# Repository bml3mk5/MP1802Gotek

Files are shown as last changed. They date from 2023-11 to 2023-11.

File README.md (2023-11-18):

# VFOインターフェース for MP-1802 / MP-1870 on 日立ベーシックマスターレベル３ / MB-S1

## フォルダ構成

    Board/ ......................... 基板設計(KiCAD Version 6)

-----
# VFO Interface for MP-1802 / MP-1870 on HITACH BASIC MASTER LEVEL3 / MB-S1

## Folders:

    Board/ ......................... Circuit board design(KiCAD Version 6)

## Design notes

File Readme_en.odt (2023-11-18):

# HITACH BASIC MASTER LEVEL3 / MB-S1

# VFO Interface for MP-1802 / MP-1870

Designed by Sasaji 2022 Rev. 0.1.2

This is an interface board connecting between a floppy disk drive and MP-1802 / MP-1870, the FD interface card on a PC.

You can use this on HITACHI BASIC MASTER LEVEL3 / Mark II / Mark5 and MB-S1.

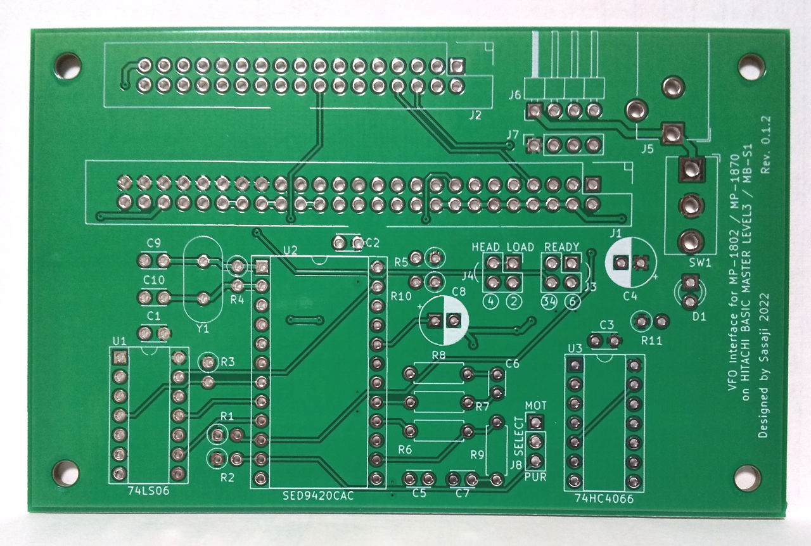
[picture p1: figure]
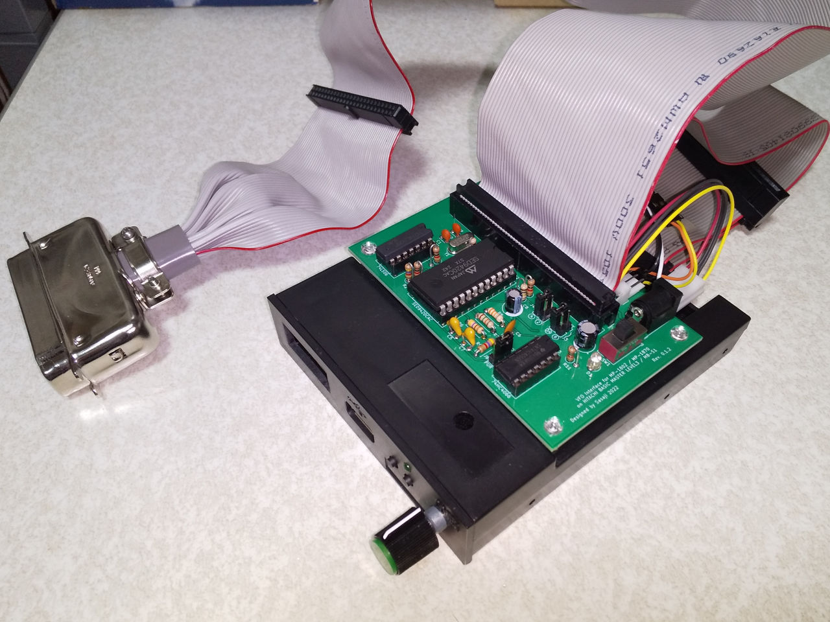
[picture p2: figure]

Connecting to the GOTEK floppy emulator

# Preparing

To use this board, you need to prepare the following :

- The FD interface card MP-1802 or MP-1870 must be present on the computer.
- FDD Emulator (GOTEK)
- Power: +5V, 1A (A switching AC adapter etc.)
- Cable to connect with the computer: 50-pin Amphenol <-> 50-pin IDC connector (2.54mm pitch x 2 rows)
- Cable to connect with FDD: 34-pin IDC connector cable (2.54mm pitch x 2 rows)

# Role of each part

Power input +5V DC Barrel Jack (Center plus) Power input +5V EI connector (+5V,Gnd,Gnd,N/C) Connect to FDD Connect to PC Power output +5V Connect to FDD (Linked with power switch) Power switch Jumper Jumper + -

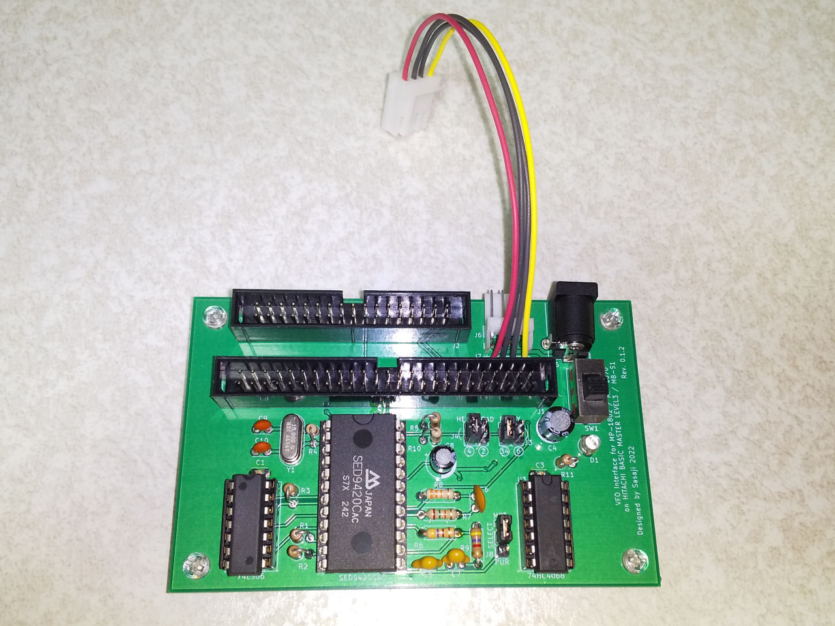
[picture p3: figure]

# Jumper pins

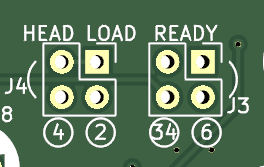
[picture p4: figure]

READY:

Select which the READY signal from the FDD is coming from.

pin34 or pin6

Short pins vertically.

HEAD LOAD:

Select which the HEAD LOAD signal from the computer is coming from.

pin4 or pin2

Short pins vertically.

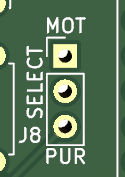
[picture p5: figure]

SELECT:

Selects the behavior of the DRIVE SELECT signal.

- MOT(Short to 1-2)：Connect the signal while the MOTOR signal is ON.
- PUR(Short to 2-3)：Always connect the signal.

# Pinout of the connector

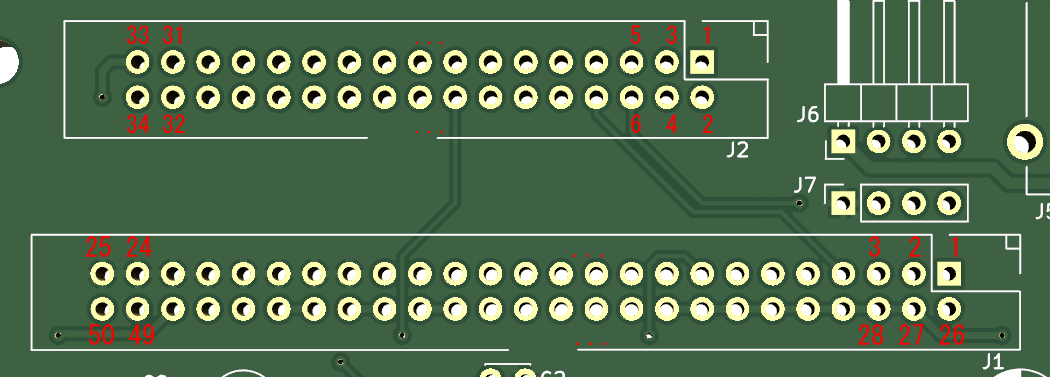
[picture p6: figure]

[Attention] The direction of silk printing is reversed. Correctly, the notch is on the upper side (pin 1 side).

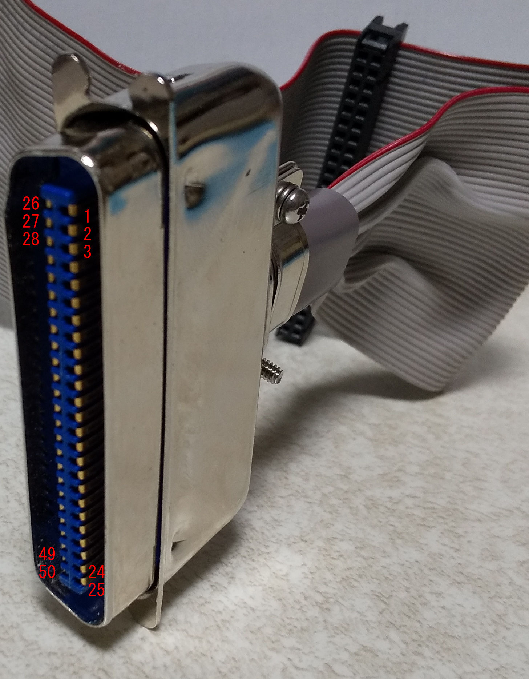
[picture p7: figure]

### When making your own 50-pin cable

There is a protrusion near pin 26 on the MP-1802/MP-1870 side, so bend this part on the cable side so that it does not hit the protrusion.

# Precautions for use

- Connect only one of the power input J5 (DC jack) and J6 (EI connector).
- Pin 4 (+12V line) of J6 is not connected to anything. When using an FDD that requires +12V, connect the power connector without going through this board.
- If the physical FDD pull-up resistance value is low, drive select may not function properly. In this case, see “About optional functions” section.
- This board is a prototype. Please note that we do not consider the noise generated during use or deterioration over time.

## No Warranty

We are not responsible for any damage caused by this board.

Use this board at your own risk.

## Web Site

GitHub(https://github.com/bml3mk5/MP1802Gotek)

Sasaji (sasaji@s-sasaji.ddo.jp)

http://s-sasaji.ddo.jp/bml3mk5/

(Twitter: https://twitter.com/bml3mk5)

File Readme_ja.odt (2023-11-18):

# 日立ベーシックマスターレベル３/ MB-S1用

# VFOインターフェース for MP-1802 / MP-1870

Designed by Sasaji 2022 Rev. 0.1.2

フロッピーディスクドライブとFDインターフェースMP-1802/MP-1870の間に接続する拡張ボードです。

日立ベーシックマスターレベル３/マークII/マーク5およびMB-S1で使用できます。


GOTEKを接続したところ

# 準備するもの

この基板を使用するには、以下のものを別途用意する必要があります。

- 本体側にFDインターフェースカード MP-1802またはMP-1870があること。
- FDDはエミュレータ(GOTEK)または2Dのもの。
- 電源：+5V, 1A以上（スイッチングACアダプタ など）
- 本体側と接続するケーブル：50ピンアンフェノール　⇔ 50ピン IDCコネクタ(2.54mmピッチ x2列)
- FDD側と接続するケーブル：34ピンIDCコネクタケーブル(2.54mmピッチ x2列)

# 各部の役割

電源入力 ＋５V DCジャック （中心が＋） 電源入力 ＋５V EIコネクタ (+5V,Gnd,Gnd,N/C) FDDと 接続 本体側と 接続 電源出力 ＋５V FDDに接続 （電源スイッチと連動） 電源スイッチ ジャンパー ジャンパー + -


# ジャンパピン


READY:

FDDからくるREADY信号がどのピンから来ているかを選択します。

ピン34 または ピン6

どちらかを縦方向にショートさせてください。

HEAD LOAD:

本体側からくるHEAD LOAD信号をどのピンに送るか選択します。

ピン4 または ピン2

どちらかを縦方向にショートさせてください。


SELECT:

DRIVE SELECT信号の挙動を選択します。

- MOT側(1-2をショート)：MOTOR信号がONのときのみFDDに接続します。
- PUR側(2-3をショート)：常にFDDに接続します。

# コネクタのピン配置


【注意】シルク印刷の向きが逆になっています。正しくは、切り欠きが上側(ピン1側)になります。


### 50ピンケーブル自作時の注意点

MP-1802/MP-1870側には、ピン26近くに出っ張りがあるため、ケーブル側はこの部分をまげて出っ張りに当たらないようにします。

# 使用上の注意

- 電源入力J5(DCジャック)とJ6(EIコネクタ)はどちらか一方のみ接続してください。
- J6のピン4(+12Vライン)はどこにも接続していません。+12Vが必要なFDDを使用する場合、電源コネクタはこの基板を経由せずに接続してください。
- 物理FDDのプルアップ抵抗値が低い場合、ドライブセレクトが正常に機能しない場合があります。この場合は「オプション機能について」に記述しているU3のピンをショートさせる処置を行ってください。
- この基板は試作品です。使用中に発生するノイズや経年劣化などに対しての考慮は全くしていませんので予めご了承ください。

## 免責事項

この基板によって発生したいかなる損害についても当方は一切責任を負いません。

この基板を使用するにあたってはすべて自己責任で行ってください。

## Webページ

この資料や基板データなどはGitHub(https://github.com/bml3mk5/MP1802Gotek)に置いています。

連絡先：

Sasaji (sasaji@s-sasaji.ddo.jp)

http://s-sasaji.ddo.jp/bml3mk5/

(Twitter: https://twitter.com/bml3mk5)

## 改訂履歴

第2版: 物理FDD使用時の注意点を追加。図内の脚注を修正。

初版: 新規作成。

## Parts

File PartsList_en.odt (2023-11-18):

# HITACH BASIC MASTER LEVEL3 / MB-S1

# VFO Interface for MP-1802 / MP-1870

Designed by Sasaji 2022 Rev. 0.1.2

# Parts list

Parts Number | Parts Name | Qty. | Description
C1~C2 | Ceramic Capacitor | 2 | 0.1uF
C4 | Electrolytic Capacitor | 1 | 100uF, 10V~
C5, C7 | Ceramic Capacitor | 2 | 0.01uF
C6 | Ceramic Capacitor | 1 | 3300pF
C8 | Electrolytic Capacitor | 1 | 22uF, 10V~
C9, C10 | Ceramic Capacitor | 2 | 22pF
R1, R3, R5, R11, R12 | Carbon Resistor | 5 | 1KΩ, 1/4W~
R2, R9 | Carbon Resistor | 2 | 4.7KΩ, 1/4W~
R4 | Carbon Resistor | 1 | 1MΩ, 1/4W~
R6 | Carbon Resistor | 1 | 470Ω, 1/4W~
R7 | Carbon Resistor | 1 | 15KΩ, 1/4W~
R8 | Carbon Resistor | 1 | 33KΩ, 1/4W~
R10 | Carbon Resistor | 1 | 100KΩ, 1/4W~
U1 | TTL Logic IC | 1 | 74LS06, DIP14
U2 | VFO IC | 1 | SED9420C or SED9420CAC DIP24, 600mil
Y1 | Crystal Oscillator | 1 | 16MHz
D1 | LED | 1 | Power Lamp 3mmΦ~
SW1 | Power Switch | 1 | SPDT SS12D10 etc.
J1 | BOX Header | 1 | 25pins x2rows 2.54mm pitch straight
J2 | BOX Header | 1 | 17pins x2rows 2.54mm pitch straight
J3, J4 | Jumper | 2 | Pinheader 2pin x2rows 2.54mmpitch straight
J5 | DC Jack | 1 | Barrel Jack 2.1mmΦ PJ-102 etc.
J6 | Power Connector | 1 | EI connector male 4pins L angled (3.5inch FDD)

## Optional Parts

C3 | Ceramic Capacitor | 1 | 0.1uF
U3 | CMOS Logic IC | 1 | 74HC4066 or 4066(*1), DIP14
J8 | Jumper | 1 | Pinheader 3pins x1row 2.54mm pitch straight
J7 | | 1 | Connect to 4 cables
* | FDD Connector | 1 | EIconnector female 4pins straight Connect from J7

(*1) See “About optional functions” section.

# Precautions for assembly

## * This board has some problems.

Connect resistor R12 between pin 3 of U1 and Vcc.

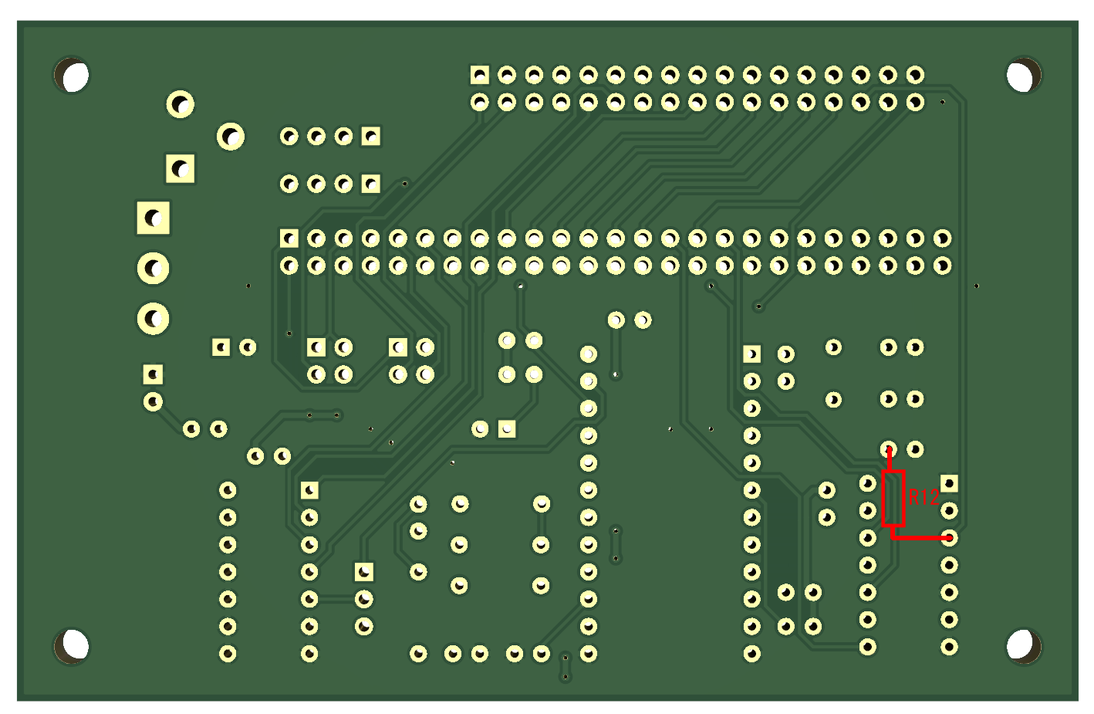
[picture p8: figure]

The notch of the BOX header is on the upper side.

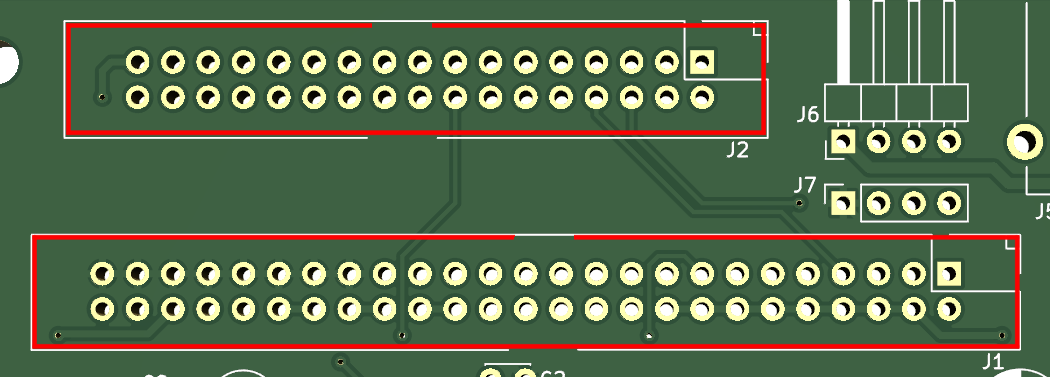
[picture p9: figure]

The anode (+) of the LED D1 is the lower side and the cathode (-) is the upper side.

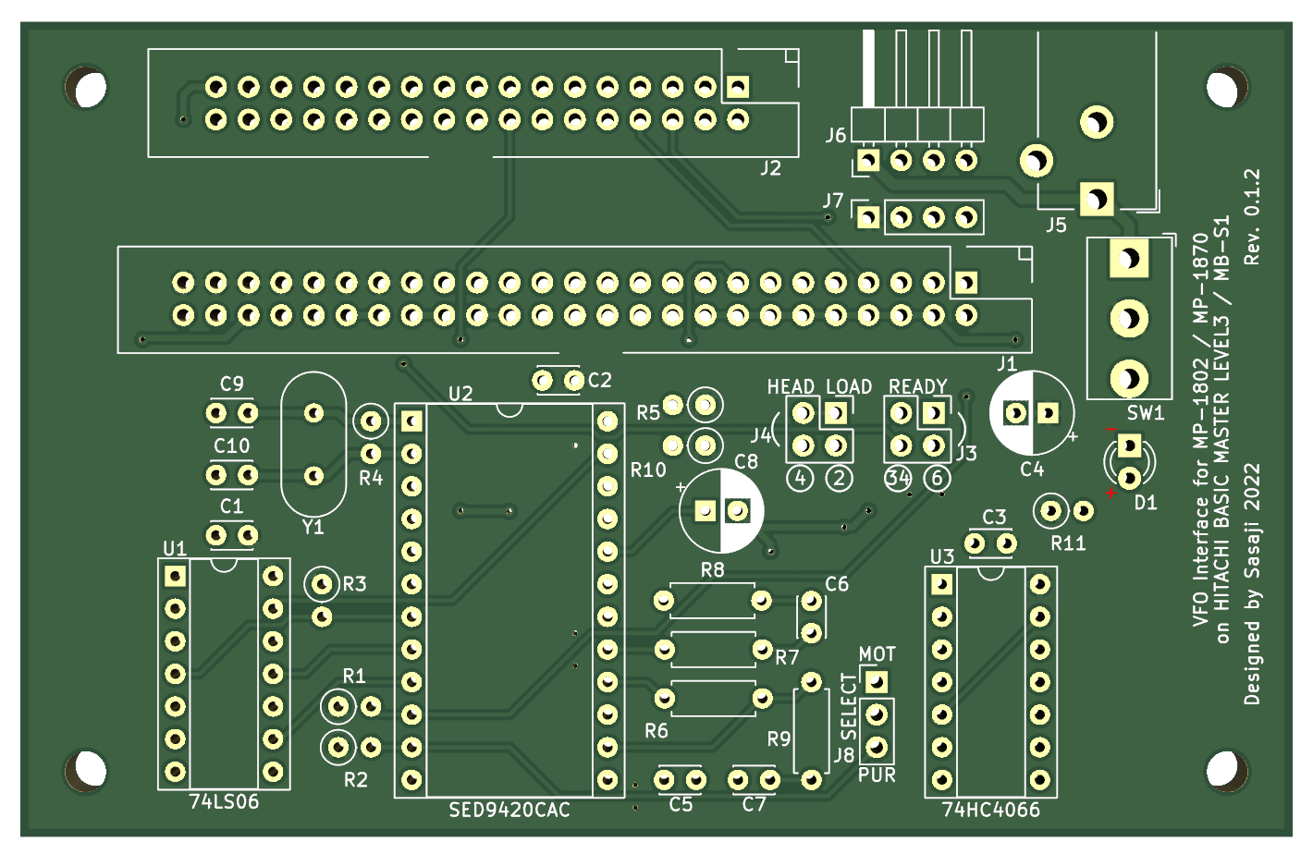
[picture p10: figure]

# About optional functions

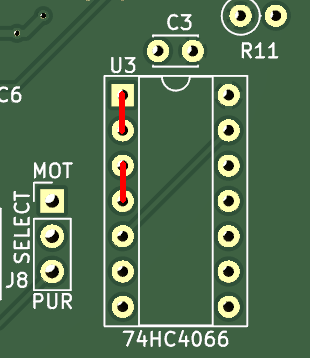
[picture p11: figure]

### About U3

The 74HC4066 (U3) connects the DRIVE SELECT signal to the FDD while the MOTOR signal is ON.

You can omit this feature if always connect it.

If omit U3:

- Short to 1-2 and 3-4 on U3.
- C3 and J8 are unnecessary.
- J8 becomes meaningless as a jumper.

[Attention] If the physical FDD pull-up resistance value is low, drive select may not function properly.

In this case, short the pin on the connecting the physical FDD (drive 0 is pin 3-4, drive 1 is pin 1-2).

### About J7

J7 is a power output for connecting to the FDD emulator (GOTEK). It works in conjunction with the power switch on this board.

pin1:+5V pin2,3:GND pin4:N/C [attention] not connected to +12V

## No Warranty

We are not responsible for any damage caused by this board.

Use this board at your own risk.

## Web Site

GitHub(https://github.com/bml3mk5/MP1802Gotek)

Sasaji (sasaji@s-sasaji.ddo.jp)

http://s-sasaji.ddo.jp/bml3mk5/

(Twitter: https://twitter.com/bml3mk5)

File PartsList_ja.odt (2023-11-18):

# 日立ベーシックマスターレベル３/ MB-S1用

# VFOインターフェース for MP-1802 / MP-1870

Designed by Sasaji 2022 Rev. 0.1.2

# 部品表

番号 | 部品名 | 数量 | 値など
C1~C2 | セラミックコンデンサ | 2 | 0.1uF
C4 | 電解コンデンサ | 1 | 100uF, 10V～
C5, C7 | セラミックコンデンサ | 2 | 0.01uF
C6 | セラミックコンデンサ | 1 | 3300pF
C8 | 電解コンデンサ | 1 | 22uF, 10V～
C9, C10 | セラミックコンデンサ | 2 | 22pF
R1, R3, R5, R11, R12 | カーボン抵抗 | 5 | 1KΩ, 1/4W～
R2, R9 | カーボン抵抗 | 2 | 4.7KΩ, 1/4W～
R4 | カーボン抵抗 | 1 | 1MΩ, 1/4W～
R6 | カーボン抵抗 | 1 | 470Ω, 1/4W～
R7 | カーボン抵抗 | 1 | 15KΩ, 1/4W～
R8 | カーボン抵抗 | 1 | 33KΩ, 1/4W～
R10 | カーボン抵抗 | 1 | 100KΩ, 1/4W～
U1 | TTLロジックIC | 1 | 74LS06, DIP14ピン
U2 | VFO IC | 1 | SED9420C または SED9420CAC DIP24ピン 600mil
Y1 | 水晶発振子 | 1 | 16MHz
D1 | LED | 1 | 電源ランプ 3mmΦ～
SW1 | 電源スイッチ | 1 | 1回路2接点 SS12D10など
J1 | BOXヘッダ | 1 | 25ピンx2列 2.54mmピッチ ストレート
J2 | BOXヘッダ | 1 | 17ピンx2列 2.54mmピッチ ストレート
J3, J4 | ジャンパ | 2 | ピンヘッダ 2ピンx2列 2.54mmピッチ ストレート
J5 | DCジャック | 1 | バレルジャック 2.1mmΦ PJ-102など
J6 | 電源コネクタ | 1 | EIコネクタ オス 4ピンx1列 Lアングル (3.5インチFDD用)

## 以下の部品はオプション

C3 | セラミックコンデンサ | 1 | 0.1uF
U3 | CMOSロジックIC | 1 | 74HC4066 または 4066(注1), DIP14ピン
J8 | ジャンパ | 1 | ピンヘッダ 3ピンx1列 2.54mmピッチ ストレート
J7 | ケーブル接続 | 1 | 4本ケーブルを接続
* | FDD接続用コネクタ | 1 | EIコネクタ メス 4ピンx1列 ストレート J7からケーブルを介して接続

(注1) 注意点は「オプション機能について」を参照のこと。

# 組立て時の注意事項

## ●この基板は設計ミスがあります。

抵抗R12は、U1のピン3とVccに間に接続してください。


## ●シルク印刷にミスがあります。

BOXヘッダの切り欠きは上側になります。


## ●その他

LED D1は下側がアノード(+)、上側がカソード(-)です。


# オプション機能について


### U3について

U3の74HC4066は、MOTOR信号がONの時のみDRIVE SELECT信号をFDDに接続するものです。

DRIVE SELECT信号を常に接続する場合は、このオプション機能は省略できます。

省略する場合：

- U3のピン1と2、ピン3と4をショートしてください。
- C3、J8は不要になります。
- J8はジャンパとしての意味を持たなくなります。

【注意】U3を使用する場合、物理FDDのプルアップ抵抗値が低いとドライブセレクトが正常に動作しない場合があります。この場合はFDDを接続しているドライブ番号側のピンをショートしてください。(ドライブ0が3-4ピン、ドライブ1が1-2ピン)

### J7について

J7はFDDエミュレータ(GOTEK)の電源ソケットに接続するための電源出力端子です。基板上の電源スイッチと連動しています。

ピン1:+5V ピン2,3:GND ピン4:未接続 【注意】+12Vとは接続していません。

## 免責事項

この基板によって発生したいかなる損害についても当方は一切責任を負いません。

この基板を使用するにあたってはすべて自己責任で行ってください。

## Webページ

この資料や基板データなどはGitHub(https://github.com/bml3mk5/MP1802Gotek)に置いています。

連絡先：

Sasaji (sasaji@s-sasaji.ddo.jp)

http://s-sasaji.ddo.jp/bml3mk5/

(Twitter: https://twitter.com/bml3mk5)

## 改訂履歴

第2版: 物理FDD使用時の注意点を追加。図内の脚注を修正。

初版: 新規作成。

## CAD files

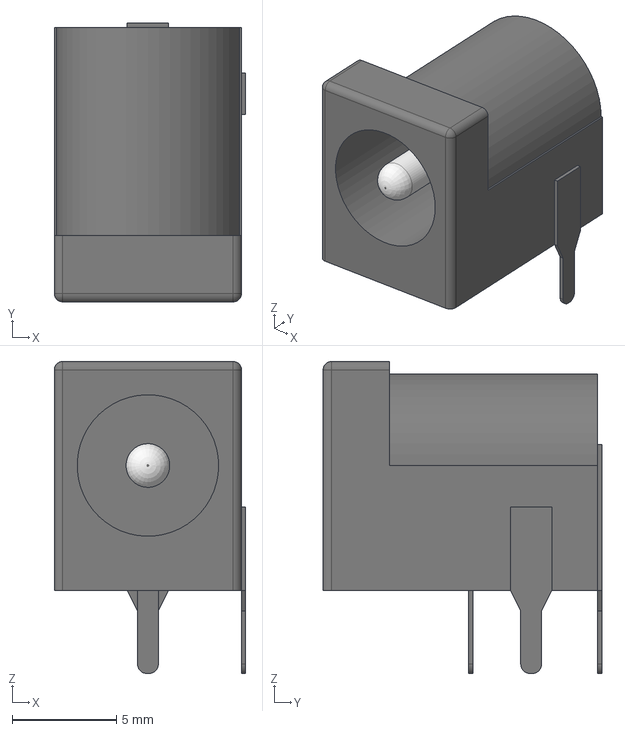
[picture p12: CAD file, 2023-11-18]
Board/DCJ21-Body.step
9.20 x 13.4 x 15.0 mm

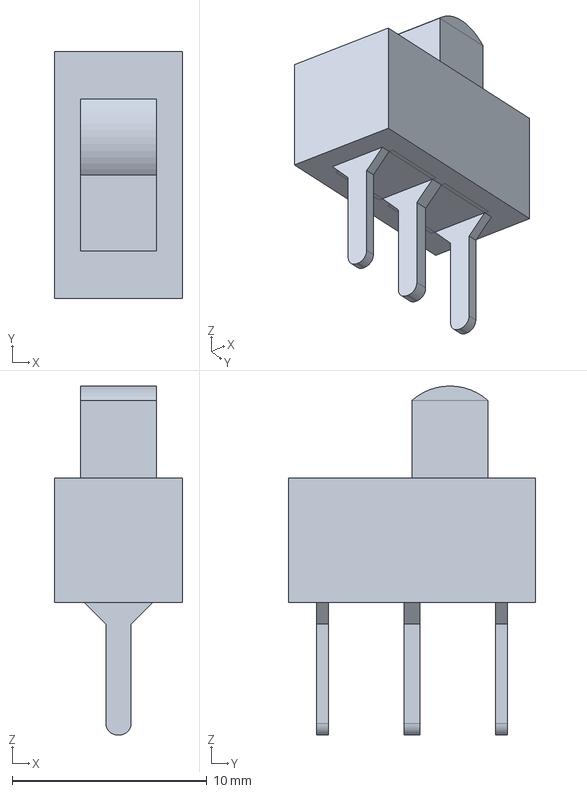
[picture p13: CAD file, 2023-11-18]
Board/SS12D10-Body.step
6.60 x 12.7 x 17.9 mm

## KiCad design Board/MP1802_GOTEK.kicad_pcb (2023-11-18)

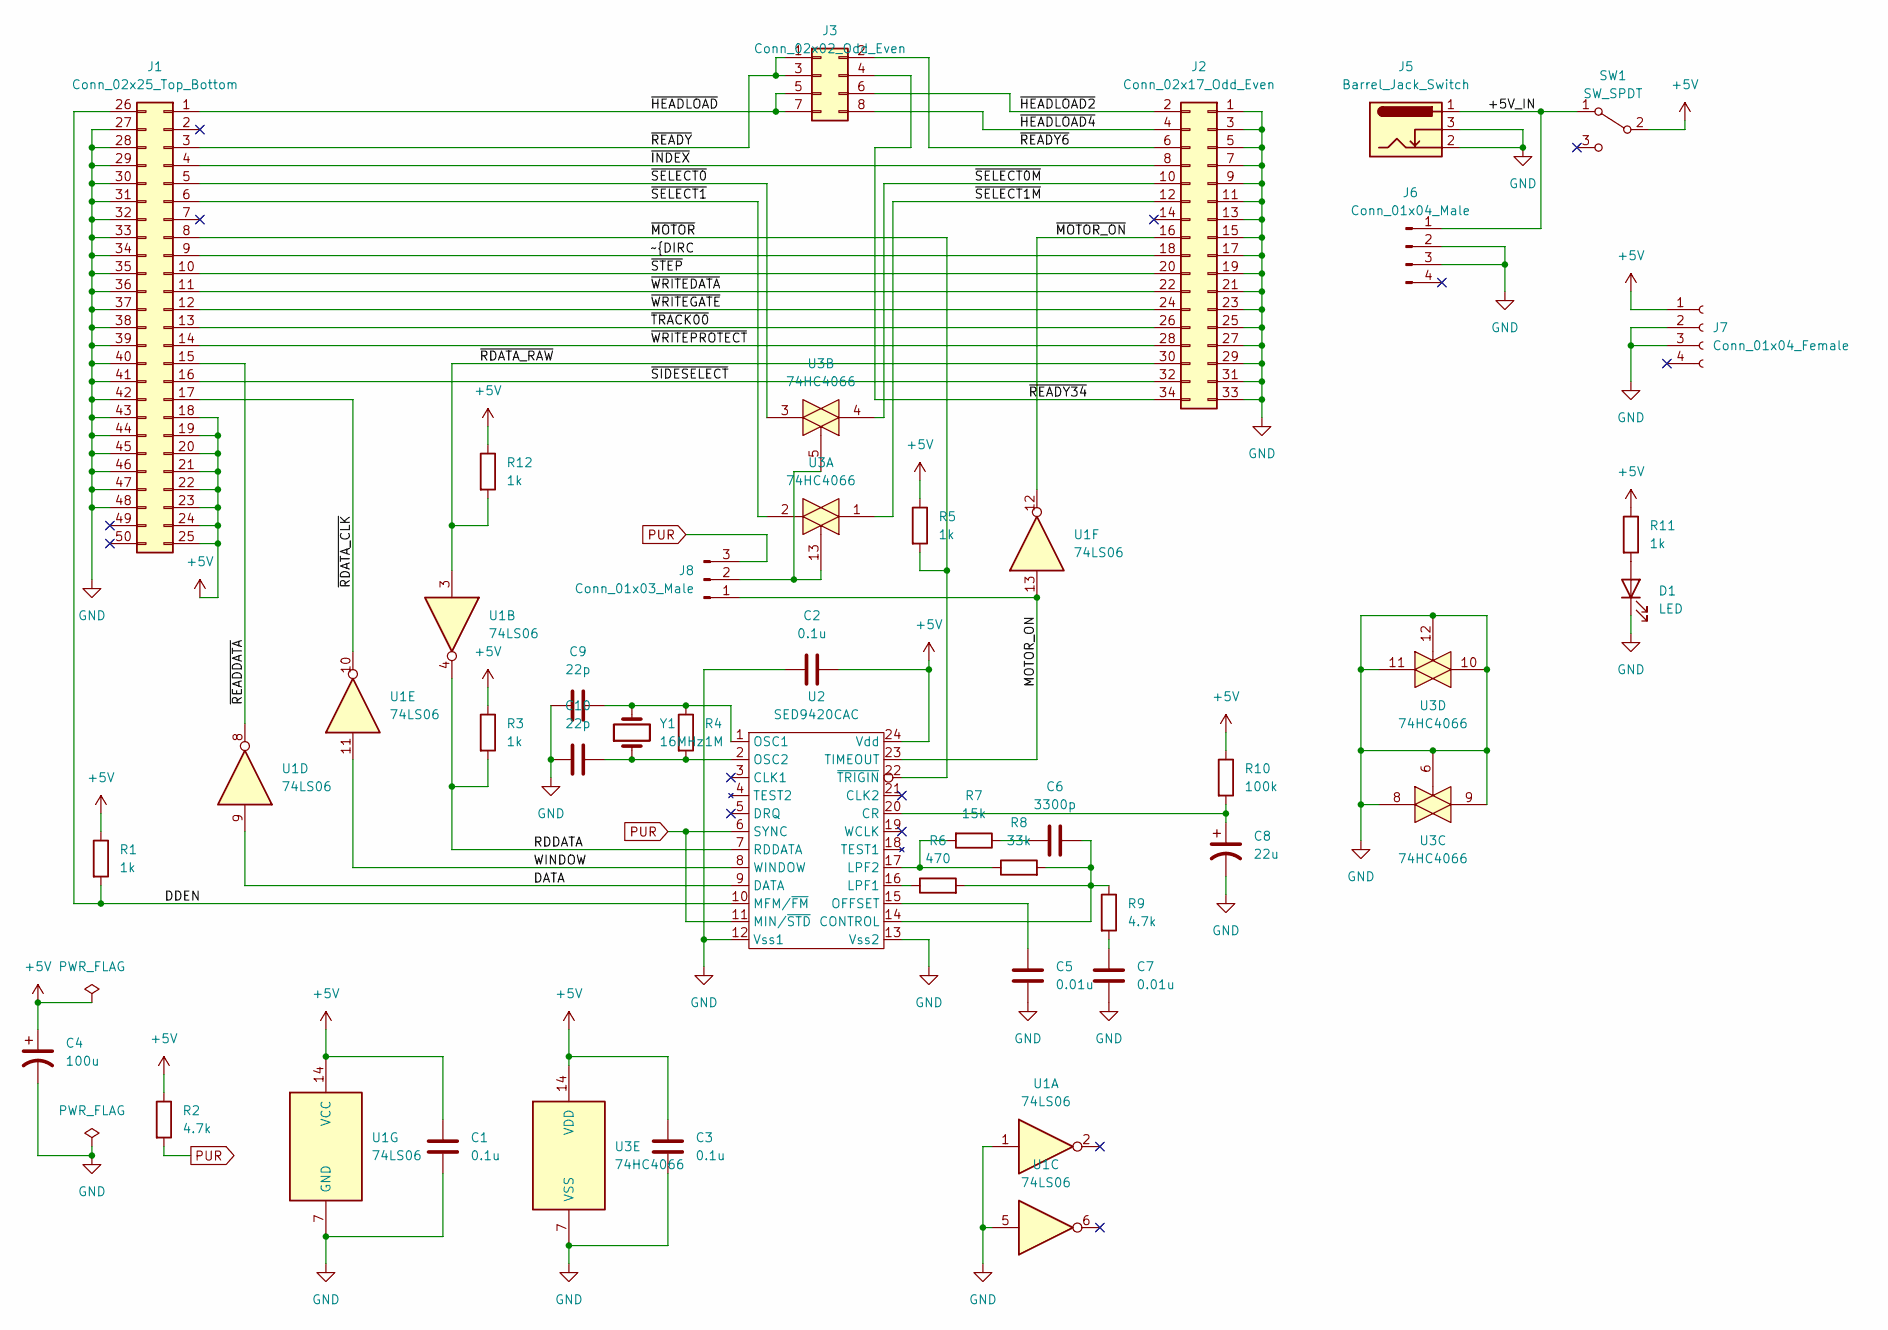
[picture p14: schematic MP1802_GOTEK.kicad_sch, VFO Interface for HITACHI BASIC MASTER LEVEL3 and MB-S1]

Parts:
C1, C2, C3: 0.1u; C_Disc_D3.0mm_W2.0mm_P2.50mm
C4: 100u; CP_Radial_D6.3mm_P2.50mm
C5, C7: 0.01u; C_Disc_D3.0mm_W2.0mm_P2.50mm
C6: 3300p; C_Disc_D3.0mm_W2.0mm_P2.50mm
C8: 22u; CP_Radial_D6.3mm_P2.50mm
C9, C10: 22p; C_Disc_D3.0mm_W2.0mm_P2.50mm
D1: LED; LED_D3.0mm
J1: Conn_02x25_Top_Bottom; YA_PinHeader_2x25_P2.54mm_Vertical
J2: Conn_02x17_Odd_Even; YA_PinHeader_2x17_P2.54mm_Vertical
J3: Conn_02x02_Odd_Even; PinHeader_2x04_P2.54mm_Vertical
J5: Barrel_Jack_Switch; YA_BarrelJack_CUI_PJ-102AH_Horizontal
J6: Conn_01x04_Male; PinHeader_1x04_P2.54mm_Horizontal
J7: Conn_01x04_Female; PinSocket_1x04_P2.54mm_Vertical
J8: Conn_01x03_Male; PinHeader_1x03_P2.54mm_Vertical
R1, R3, R5, R11, R12: 1k; R_Axial_DIN0207_L6.3mm_D2.5mm_P2.54mm_Vertical
R2: 4.7k; R_Axial_DIN0207_L6.3mm_D2.5mm_P2.54mm_Vertical
R4: 1M; R_Axial_DIN0207_L6.3mm_D2.5mm_P2.54mm_Vertical
R6: 470; R_Axial_DIN0207_L6.3mm_D2.5mm_P7.62mm_Horizontal
R7: 15k; R_Axial_DIN0207_L6.3mm_D2.5mm_P7.62mm_Horizontal
R8: 33k; R_Axial_DIN0207_L6.3mm_D2.5mm_P7.62mm_Horizontal
R9: 4.7k; R_Axial_DIN0207_L6.3mm_D2.5mm_P7.62mm_Horizontal
R10: 100k; R_Axial_DIN0207_L6.3mm_D2.5mm_P2.54mm_Vertical
SW1: SW_SPDT; SW_Switch_SS12D10_SPDT
U1: 74LS06; DIP-14_W7.62mm_Socket
U2: SED9420CAC; DIP-24_W15.24mm_Socket
U3: 74HC4066; DIP-14_W7.62mm_Socket
Y1: 16MHz; Crystal_HC18-U_Vertical

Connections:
+5V: C1.2, C2.2, C3.2, C4.1, J1.18, J1.19, J1.20, J1.21, J1.22, J1.23, J1.24, J1.25, J7.1, R1.1, R2.1, R3.1, R5.1, R10.1, R11.1, R12.1, SW1.2 (B), U1.14 (VCC), U2.24 (Vdd), U3.14 (VDD)
/+5V_IN: J5.1, J6.1, SW1.1 (A)
/DATA: U1.9, U2.9 (DATA)
/DDEN: J1.26, R1.2, U2.10 (MFM/~FM)
/MOTOR_ON: J8.1, U1.13, U2.23 (TIMEOUT)
/RDDATA: R3.2, U1.4, U2.7 (RDDATA)
/WINDOW: U1.11, U2.8 (WINDOW)
/~DIRC: J1.9, J2.18
/~HEADLOAD2: J2.2, J3.6
/~HEADLOAD4: J2.4, J3.8
/~HEADLOAD: J1.1, J3.5, J3.7
/~INDEX: J1.4, J2.8
/~MOTOR_ON: J2.16, U1.12
/~MOTOR: J1.8, R5.2, U2.22 (~TRIGIN)
/~RDATA_CLK: J1.17, U1.10
/~RDATA_RAW: J2.30, R12.2, U1.3
/~READDATA: J1.15, U1.8
/~READY6: J2.6, J3.2
/~READY34: J2.34, J3.4
/~READY: J1.3, J3.1, J3.3
/~SELECT0M: J2.10, U3.4
/~SELECT0: J1.5, U3.3
/~SELECT1M: J2.12, U3.1
/~SELECT1: J1.6, U3.2
/~SIDESELECT: J1.16, J2.32
/~STEP: J1.10, J2.20
/~TRACK00: J1.13, J2.26
/~WRITEDATA: J1.11, J2.22
/~WRITEGATE: J1.12, J2.24
/~WRITEPROTECT: J1.14, J2.28
GND: C1.1, C2.1, C3.1, C4.2, C5.1, C7.1, C8.2, C9.1, C10.1, D1.1 (K), J1.27, J1.28, J1.29, J1.30, J1.31, J1.32, J1.33, J1.34, J1.35, J1.36, J1.37, J1.38, J1.39, J1.40, J1.41, J1.42, J1.43, J1.44, J1.45, J1.46, J1.47, J1.48, J2.1, J2.3, J2.5, J2.7, J2.9, J2.11, J2.13, J2.15, J2.17, J2.19, J2.21, J2.23, J2.25, J2.27, J2.29, J2.31, J2.33, J5.2, J5.3, J6.2, J6.3, J7.2, J7.3, U1.1, U1.5, U1.7 (GND), U2.12 (Vss1), U2.13 (Vss2), U3.6, U3.7 (VSS), U3.8, U3.9, U3.10, U3.11, U3.12
unnamed: C5.2, U2.15 (OFFSET)
unnamed: C6.1, R7.1
unnamed: C6.2, R6.2, R8.2, R9.1, U2.14 (CONTROL)
unnamed: C7.2, R9.2
unnamed: C8.1, R10.2, U2.20 (CR)
unnamed: C9.2, R4.1, U2.1 (OSC1), Y1.2
unnamed: C10.2, R4.2, U2.2 (OSC2), Y1.1
unnamed: D1.2 (A), R11.2
unnamed: J8.2, U3.5, U3.13
unnamed: R6.1, U2.16 (LPF1)
unnamed: R7.2, R8.1, U2.17 (LPF2)
PUR: J8.3, R2.2, U2.6 (SYNC), U2.11 (MIN/~STD)

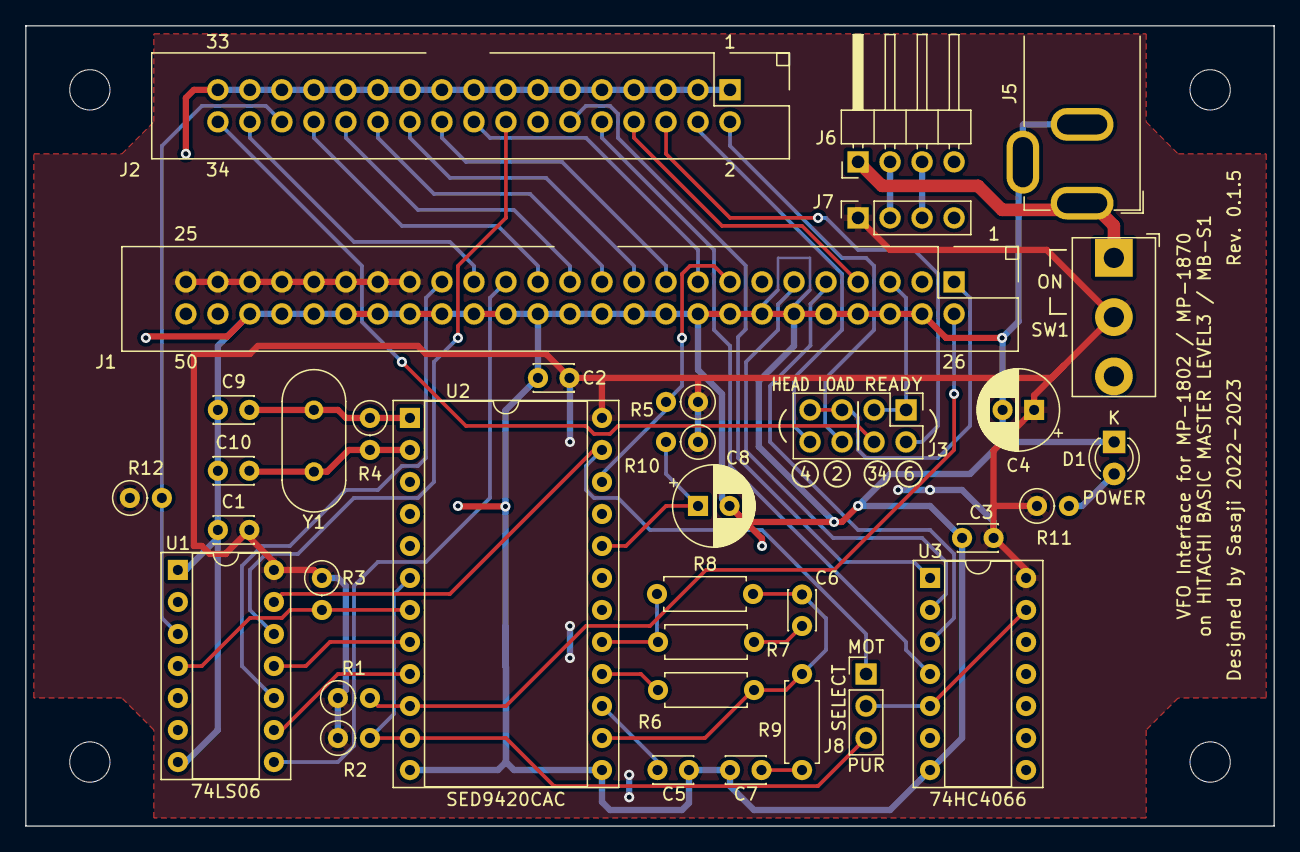
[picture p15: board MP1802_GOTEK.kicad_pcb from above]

Board: 2 copper layers, 99.1 x 63.5 mm, 35 parts (0 on the bottom side), 43 nets.

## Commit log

2023-11-18 Version 0.1.2
    [MP1802_GOTEK.kicad_pcb, MP1802_GOTEK.kicad_sch]
2023-11-18 Revision 0.1.5
    [DCJ21-Body.step, MP1802_GOTEK.kicad_pcb, MP1802_GOTEK.kicad_sch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]
